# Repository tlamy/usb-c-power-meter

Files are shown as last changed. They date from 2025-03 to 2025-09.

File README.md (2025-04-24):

USB-C Power Meter Firmware

# Sources

The source code is single file and straightforward as it's only one file, main.cpp.

My current development environment is CLion using PlatformIO. As this is not easily replicable (there is no free CLion
version), I also provide premade binaries.

# Binaries

In /firmware_bin, you can find a number of premade, you guessed it, binaries.
They are named from this pattern:

**firmware_\<version\>_\<resistance\>.bin**

<a href="firmware_bin/firmware_v1.1.3_10mohm.bin">firmware_v1.1.3_10mohm.bin</a> is the first github released binary, as
I sent out a couple of meters having the wrong shunt resistor soldered on, effectively maxing out the current sensor at
around 1.6A. This version is to be used with a replacement shunt resistor of .01Ω, or 10mΩ.

## Uploading firmware

If you're unable to build it yourself, you should
follow <a href="https://github.com/SequoiaSan/Guide-How-To-Upload-bin-to-ESP8266-ESP32">SequoiaSan's guide</a> on
Github.

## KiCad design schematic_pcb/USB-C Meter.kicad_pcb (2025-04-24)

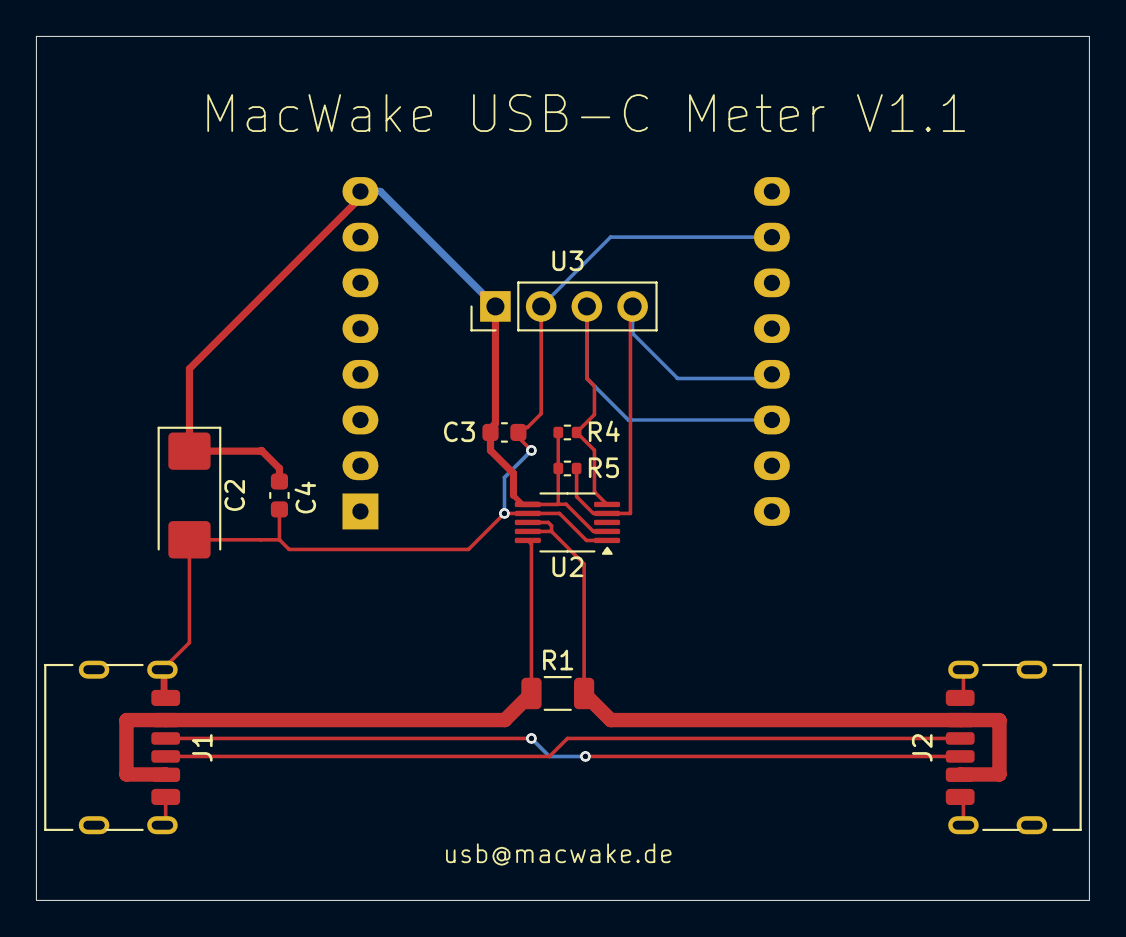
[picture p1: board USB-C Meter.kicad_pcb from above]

Board: 2 copper layers, 58.5 x 48.0 mm, 11 parts (1 on the bottom side), 8 nets.

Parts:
C2: 20µ; CP_EIA-6032-20_AVX-F
C3, C4: 0.1µ; C_0603_1608Metric
J1, J2: USB_C_Receptacle_PowerOnly_6P; USB_C_Receptacle_HRO_TYPE-C-31-M-17
R1: 0.01R 3W; R_1206_3216Metric
R4, R5: 3k3; R_0402_1005Metric
U1: WEMOS_D1_mini; WEMOS_D1_mini_light
U2: INA226; VSSOP-10_3x3mm_P0.5mm
U3: Display I2C; PinHeader_1x04_P2.54mm_Vertical

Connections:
unnamed: J1.A5 (CC1), J2.A5 (CC1)
unnamed: J1.B5 (CC2), J2.B5 (CC2)
unnamed: C2.2, C3.2, C4.1, J1.A12 (GND), J1.B12 (GND), J1.S1 (SHIELD), J2.A12 (GND), J2.B12 (GND), J2.S1 (SHIELD), U1.10 (GND), U2.1 (A1), U2.7 (GND), U3.2 (GND)
unnamed: C2.1, C3.1, C4.2, R4.2, R5.2, U1.8 (3V3), U2.2 (A0), U2.6 (VS), U3.1 (VDD)
unnamed: R4.1, U1.14 (SCL/D1), U2.5 (SCL), U3.3 (SCL)
unnamed: R5.1, U1.13 (SDA/D2), U2.4 (SDA), U3.4 (SDA)
unnamed: J2.A9 (VBUS), J2.B9 (VBUS), R1.2, U2.8 (Vbus), U2.9 (Vin-)
unnamed: J1.A9 (VBUS), J1.B9 (VBUS), R1.1, U2.10 (Vin+)

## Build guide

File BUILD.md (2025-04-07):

# Building

## macOS
* `brew install platformio`
*

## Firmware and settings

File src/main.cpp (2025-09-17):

#include <Arduino.h>
#include <INA226_WE.h>
#include <U8g2lib.h>
#include <Wire.h>

#define MY_BLUE_LED_PIN D4
#define RELEASE_VERSION "1.2.2"

#define DEBUG_LED_PEAK_DETECT 0
#define DEBUG_INA 0
#define SCREENSAVER_DELAY 10000

U8G2_SH1106_128X64_NONAME_F_HW_I2C u8g2(U8G2_R0);
INA226_WE ina226;

void splash() {
  char buf[64];
  u8g2.firstPage();
  u8g2.setFont(u8g2_font_profont29_tr);
  sprintf(buf, "MacWake");
  u8g2.drawStr((u8g2.getDisplayWidth() - u8g2.getStrWidth(buf)) / 2,
               (u8g2.getDisplayHeight() / 2) + u8g2.getFontAscent() / 2, buf);
  u8g2.setFont(u8g2_font_profont12_tr);
  sprintf(buf, "USB Power Meter");
  u8g2.drawStr((u8g2.getDisplayWidth() - u8g2.getStrWidth(buf)) / 2,
               (u8g2.getDisplayHeight() / 2) + u8g2.getFontAscent() / 2 + 16,
               buf);
  u8g2.setFont(u8g2_font_profont10_tr);
  sprintf(buf, "V%s", RELEASE_VERSION);
  u8g2.drawStr((u8g2.getDisplayWidth() - u8g2.getStrWidth(buf)) / 2, 62, buf);
  u8g2.nextPage();
  delay(1500);
}

static void scan_i2c() {
  uint8_t error, address;
  int nDevices;
  Serial.println("Scanning for devices...");
  nDevices = 0;
  for (address = 1; address < 127; address++) {
    Wire.beginTransmission(address);
    error = Wire.endTransmission();
    if (error == 0) {
      nDevices++;
      Serial.print("I2C device found at address 0x");
      if (address < 16)
        Serial.print("0");
      Serial.println(address, HEX);
    }
  }
  Serial.println("done\n");
  Serial.print("Found ");
  Serial.print(nDevices);
  Serial.println(" devices.");
}

static uint8_t findInaAddress() {
  uint8_t error, address;

  for (address = 0x40; address < 0x48; address++) {
    Wire.beginTransmission(address);
    error = Wire.endTransmission();
    if (error == 0) {
      return address;
    }
  }
  return 0;
}
void setup() {
  Serial.begin(9600);
  Serial.println();
  Serial.printf("MacWake USB-Power V%s\n", RELEASE_VERSION);

  pinMode(MY_BLUE_LED_PIN,
          OUTPUT); // Initialize the LED_BUILTIN pin as an output

  u8g2.begin();

  Wire.begin();

  uint8_t ina_address = findInaAddress();
  if (ina_address == 0) {
    Serial.println("INA226 not found");
    scan_i2c();
    delay(10000);
    while (1)
      ; // halt
  }
  ina226 = INA226_WE(&Wire, ina_address);
  if (!ina226.init()) {
    Serial.println("INA226 init failed");
    scan_i2c();
    delay(10000);
    while (1)
      ; // halt
  }
  ina226.setAverage(AVERAGE_16);
  ina226.setConversionTime(CONV_TIME_2116);
  ina226.setMeasureMode(CONTINUOUS);
  ina226.setResistorRange(0.01, 6.0);
  ina226.setCorrectionFactor(0.975); // must be aligned with good load

  splash();
}

char hexdigit(uint8_t nibble) {
  return nibble < 10 ? nibble + '0' : nibble - 10 + 'A';
}

void int2hex(int16_t val, char *buf) {
  buf[0] = hexdigit((highByte(val) >> 4) & 0x0f);
  buf[1] = hexdigit((highByte(val)) & 0x0f);
  buf[2] = hexdigit((lowByte(val) >> 4) & 0x0f);
  buf[3] = hexdigit((lowByte(val)) & 0x0f);
}

void serial_out(int milliamps, int millivolt) {
  float shuntval = -milliamps / 0.2;
  float voltval = millivolt / 3.125;
  int16_t shunt_ser = shuntval;
  int16_t volt_ser = voltval;

  char buf[16];
  int2hex(shunt_ser, buf);
  int2hex(volt_ser, buf + 4);
  buf[8] = 28;
  buf[9] = '\n';
  buf[10] = '\0';
  Serial.print(buf);
}

void read_ina(int *shunt, int *millivolt, int *current) {
  float shuntVoltage_mV = 0.0;
  float busVoltage_V = 0.0;
  float current_mA = 0.0;

  ina226.readAndClearFlags();
  shuntVoltage_mV = ina226.getShuntVoltage_mV();
  busVoltage_V = ina226.getBusVoltage_V();
  current_mA = ina226.getCurrent_mA();
#if DEBUG_INA
  float power_mW = ina226.getBusPower();
  float loadVoltage_V = busVoltage_V + (shuntVoltage_mV / 1000);

  Serial.print("Shunt Voltage [mV]: ");
  Serial.println(shuntVoltage_mV);
  Serial.print("Bus Voltage [V]: ");
  Serial.println(busVoltage_V);
  Serial.print("Load Voltage [V]: ");
  Serial.println(loadVoltage_V);
  Serial.print("Current[mA]: ");
  Serial.println(current_mA);
  Serial.print("Bus Power [mW]: ");
  Serial.println(power_mW);
  if (ina226.overflow) {
    Serial.println("! OVERFLOW !");
  }
  if (ina226.convAlert) {
    Serial.println("! CONVALERT !");
  }
  if (ina226.limitAlert) {
    Serial.println("! LIMIT_ALERT !");
  }
  Serial.println();
#endif
  *shunt = static_cast<int>(shuntVoltage_mV);
  *millivolt = static_cast<int>(busVoltage_V * 1000.0);
  *current = static_cast<int>(current_mA);
}

uint8_t normalize_volt(int millivolt) {
  if (millivolt < 1000)
    return 0;
  if (millivolt < 6500)
    return 5;
  if (millivolt < 11000)
    return 9;
  if (millivolt < 17000)
    return 16;
  if (millivolt < 22000)
    return 20;
  if (millivolt < 30000)
    return 28;
  if (millivolt < 39000)
    return 36;
  return 48;
}

#define AMP_BUF_SIZE 32
uint8_t last_volts = 0;
int last_currents[AMP_BUF_SIZE];
uint8_t current_ptr = 0;

int get_max_current(int current, uint8_t volts) {
  static int max_current = 0;
  int absCurrent = abs(current);
  if (volts != last_volts) {
    current_ptr = 0;
    for (int & last_current : last_currents) {
      last_current = 0;
    }
    last_volts = volts;
    max_current = 0;
  }
  if (max_current > 0 && last_currents[current_ptr] == max_current) {
    // digitalWrite(MY_BLUE_LED_PIN, LOW); // Turn the LED on (Note that LOW is
    // the voltage level
    last_currents[current_ptr] = absCurrent;
    max_current = 0;
    for (const int last_current : last_currents) {
      if (last_current > max_current)
        max_current = last_current;
    }
  } else {
    last_currents[current_ptr] = absCurrent;
    if (absCurrent > max_current) {
      max_current = absCurrent;
    }
  }
  current_ptr = (current_ptr + 1) % AMP_BUF_SIZE;
  return max_current;
}

void screensaver(int *x, int *y) {
  static int last_x = 1, last_y = 2;
  static signed char x_dir = 3, y_dir = 2;

  *x = last_x + x_dir;
  if (*x > 127) {
    x_dir = -x_dir;
    *x = 126;
  } else if (*x < 0) {
    x_dir = -x_dir;
    *x = 0;
  }
  *y = last_y + y_dir;
  if (*y > 63) {
    y_dir = -y_dir;
    *y = 62;
  } else if (*y < 0) {
    y_dir = -y_dir;
    *y = 0;
  }
  last_x = *x;
  last_y = *y;
}

void display(int millivolt, uint8_t volt_norm, int milliamps, int maxcurrent) {
  char buf[32];
  char buf2[32];
  static unsigned long last_millis = 0;

  u8g2.firstPage();
  do {
    u8g2.setFont(u8g2_font_profont17_tr);
    if (volt_norm == 0 && last_millis < millis() - SCREENSAVER_DELAY) {
      int x, y;
      screensaver(&x, &y);
      u8g2.drawPixel(x, y);
      continue;
    }
    if (volt_norm != 0) {
      last_millis = millis();
    }
    float amps = static_cast<float>(milliamps) / 1000.0F;
    float volts = static_cast<float>(millivolt) / 1000.0F;

    // if (volt_norm == 5)
    //   u8g2.drawStr(10, 17, "5V");
    // else if (volt_norm == 9)
    //   u8g2.drawStr(25, 17, "9V");
    // else if (volt_norm == 15)
    //   u8g2.drawStr(40, 17, "15V");
    // else if (volt_norm == 20)
    //   u8g2.drawStr(55, 17, "20V");
    // else if (volt_norm == 28)
    //   u8g2.drawStr(70, 17, "28V");
    // else if (volt_norm == 36)
    //   u8g2.drawStr(85, 17, "36V");
    // else if (volt_norm == 48)
    //   u8g2.drawStr(100, 17, "48V");
    sprintf(buf, "%0.2fV", volts);
    u8g2.drawStr(0, 17, buf);
    sprintf(buf, "%0.2fW", volts * amps);
    u8g2.drawStr(128 - u8g2.getStrWidth(buf), 17, buf);

    u8g2.setFont(u8g2_font_profont12_tr);
    sprintf(buf, "%0.3fA", ((float)maxcurrent / 1000.0F));
    u8g2.drawStr(127 - u8g2.getStrWidth(buf), 32, buf);
    u8g2.drawLine(127, 33, 127, 35);
    int bar = (int)((float)128 * ((float)abs(milliamps) / (float)maxcurrent));
    u8g2.drawLine(0, 34, bar, 34);

    u8g2.setFont(u8g2_font_profont29_tr);
    sprintf(buf2, "%0.3fA", amps);
    u8g2.drawStr(128 - u8g2.getStrWidth(buf2), 62, buf2);
  } while (u8g2.nextPage());
}

void loop() {
  int millivolt;
  int shunt;
  int current;

  digitalWrite(MY_BLUE_LED_PIN,
               HIGH); // Turn the LED on (Note that LOW is the voltage level

  read_ina(&shunt, &millivolt, &current);
  uint8_t volt_norm = normalize_volt(millivolt);

  serial_out(current, millivolt);

  int max_current = get_max_current(current, volt_norm);

  display(millivolt, volt_norm, current, max_current);

  delay(50);
}

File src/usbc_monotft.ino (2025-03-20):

#include <Arduino.h>
#include <SPI.h>
#include <U8g2lib.h>
#include <Wire.h>
#include <INA226_WE.h>
#define INA_I2C_ADDRESS 0x41
#define MY_BLUE_LED_PIN D4

U8G2_SH1106_128X64_NONAME_F_HW_I2C u8g2(U8G2_R0);
INA226_WE ina226 = INA226_WE(&Wire, INA_I2C_ADDRESS);

void splash() {
  char buf[64];
  u8g2.firstPage();
  u8g2.setFont(u8g2_font_profont29_tr);
  sprintf(buf, "MacWake");
  u8g2.drawStr((u8g2.getDisplayWidth()-u8g2.getStrWidth(buf))/2, (u8g2.getDisplayHeight()/2)+u8g2.getFontAscent()/2, buf);
  u8g2.nextPage();
  delay(1000);
}
void setup() {
  Serial.begin(9600);
  Serial.println();
  Serial.println("MacWake USB-Power V1.0");

  pinMode(MY_BLUE_LED_PIN, OUTPUT);     // Initialise the LED_BUILTIN pin as an output

  u8g2.begin();
  randomSeed(analogRead(A0));

  Wire.begin();
  ina226.init();
  ina226.setAverage(AVERAGE_4);
  ina226.setConversionTime(CONV_TIME_2116);
  ina226.setMeasureMode(CONTINUOUS);
  ina226.setResistorRange(0.01,20.0);
  ina226.setCorrectionFactor(0.95); // must be aligned with good load

  splash();
}

char hexdigit(uint8_t nibble) {
  return nibble < 10 ? nibble+'0' : nibble-10+'A';
}
void int2hex(int16_t val, char *buf) {
  buf[0] = hexdigit((highByte(val)>>4) & 0x0f);
  buf[1] = hexdigit((highByte(val)) & 0x0f);
  buf[2] = hexdigit((lowByte(val)>>4) & 0x0f);
  buf[3] = hexdigit((lowByte(val)) & 0x0f);
}
void serial_out(int shunt, int millivolt) {
  float shuntval = -shunt/0.2;
  float voltval = millivolt/3.125;
  int16_t shunt_ser = shuntval;
  int16_t volt_ser = voltval;

  char buf[16];
  int2hex(shunt_ser, buf);
  int2hex(volt_ser, buf+4);
  buf[8] = 28;
  buf[9] = '\n';
  buf[10] = '\0';
  Serial.print(buf);
}

void read_ina(int *shunt, int *millivolt) {
//  float shuntVoltage_mV = 0.0;
//  float loadVoltage_V = 0.0;
  float busVoltage_V = 0.0;
  float current_mA = 0.0;
//  float power_mW = 0.0;

  ina226.readAndClearFlags();
//  shuntVoltage_mV = ina226.getShuntVoltage_mV();
  busVoltage_V = ina226.getBusVoltage_V();
  current_mA = ina226.getCurrent_mA();
//  power_mW = ina226.getBusPower();
//  loadVoltage_V  = busVoltage_V + (shuntVoltage_mV/1000);

//  Serial.print("Shunt Voltage [mV]: "); Serial.println(shuntVoltage_mV);
//  Serial.print("Bus Voltage [V]: "); Serial.println(busVoltage_V);
//  Serial.print("Load Voltage [V]: "); Serial.println(loadVoltage_V);
//  Serial.print("Current[mA]: "); Serial.println(current_mA);
//  Serial.print("Bus Power [mW]: "); Serial.println(power_mW);
//  if(!ina226.overflow){
//    Serial.println("Values OK - no overflow");
//  }
//  else{
//    Serial.println("Overflow! Choose higher current range");
//  }
//  Serial.println();
  *shunt = current_mA/2;
  *millivolt = busVoltage_V*1000;
}

uint8_t normalize_volt(int millivolt) {
  if(millivolt < 1000)
    return 0;
  if(millivolt < 6000)
    return 5;
  if(millivolt < 10000)
    return 9;
  if(millivolt < 16000)
    return 16;
  if(millivolt < 21000)
    return 20;
  if(millivolt < 29000)
    return 28;
  if(millivolt < 37000)
    return 36;
   return 48;
}
#define AMP_BUF_SIZE 32
uint8_t last_volts = 0;
int last_currents[AMP_BUF_SIZE];
uint8_t current_ptr=0;
int max_current = 0;

int get_max_current(int current, uint8_t volts) {
  if(volts != last_volts) {
    current_ptr=0;
    for(int i=0; i < AMP_BUF_SIZE; ++i) {
      last_currents[i]=0;
    }
    last_volts = volts;
    max_current = 0;
  }
  if(max_current > 0 && last_currents[current_ptr] == max_current) {
      digitalWrite(MY_BLUE_LED_PIN, LOW);   // Turn the LED on (Note that LOW is the voltage level
      last_currents[current_ptr] = current;
      max_current = 0;
      for(int i=0; i < AMP_BUF_SIZE; ++i) {
        if(last_currents[i]>max_current) max_current = last_currents[i];
      }
  } else {
    last_currents[current_ptr] = current;
    if(current > max_current) {
      max_current = current;
    }
  }
  current_ptr = (current_ptr+1)%AMP_BUF_SIZE;
  return max_current;
}

void display(uint8_t volt_norm, int shunt, int maxcurrent) {
  char buf[32];
  char buf2[32];
  u8g2.firstPage();
  do {
    u8g2.setFont(u8g2_font_profont17_tf);
    if(volt_norm == 0)
      u8g2.drawStr(0, 17,  "-");
    else if(volt_norm == 5)
      u8g2.drawStr(10, 17, "5V");
    else if(volt_norm == 9)
      u8g2.drawStr(30, 17, "9V");
    else if(volt_norm == 15)
      u8g2.drawStr(50, 17, "15V");
    else if(volt_norm == 20)
      u8g2.drawStr(70, 17, "20V");
    else if(volt_norm == 28)
      u8g2.drawStr(90, 17,  "28V");
    else if(volt_norm == 36)
      u8g2.drawStr(100, 17,  "36V");

    sprintf(buf, "%0.3fA", ((float)maxcurrent/1000.0));
    u8g2.drawStr(128-u8g2.getStrWidth(buf),33,buf);

    u8g2.setFont(u8g2_font_profont29_mf);
    float amps = ((float)shunt/1000.0);
    sprintf(buf2, "%0.3fA", amps);
    u8g2.drawStr(128-u8g2.getStrWidth(buf2),60,buf2);

  } while ( u8g2.nextPage() );
}
void loop() {
  int millivolt;
  int shunt;

      digitalWrite(MY_BLUE_LED_PIN, HIGH);   // Turn the LED on (Note that LOW is the voltage level

read_ina(&shunt, &millivolt);
uint8_t volt_norm = normalize_volt(millivolt);
//  float randomNumber = 500 + random(1500);
//  shunt = (int)randomNumber;
//  if(millis() < 15000) {
//    millivolt = 5000 + (random(200))-100;
//  } else {
//    millivolt = 20000 + (random(200))-100;
//  }

  serial_out(shunt,millivolt);

  int max_current = get_max_current(shunt,volt_norm);

  display(volt_norm, shunt, max_current);

  delay(100);
}

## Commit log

2025-03-22 feat: first commit after switching to clion
2025-03-22 feat: Implemented current bar
2025-04-16 fix: remove LED debugging for max amp calculation/reset
    [main.cpp]
2025-04-24 Added schematic and pcb (kicad)
    [USB-C Meter.kicad_pcb, USB-C Meter.kicad_sch]
2025-04-26 fix: explicitly mark as 10 mOhm version
    [main.cpp]
2025-09-17 fix(d1mini): some INAs are on 0x45 instead of the configured 0x41
    [main.cpp]
2025-09-17 fix(firmware): screensaver with delay, watts display, handle negative current properly
    [main.cpp]
